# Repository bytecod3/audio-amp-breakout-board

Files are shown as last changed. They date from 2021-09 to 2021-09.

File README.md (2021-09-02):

## Class AB Audio Amplifier With TDA2030
### Introduction
The amplifier shown below uses the very versatile monolithic IC TDA2030 audio amplifier
to amplify the audio input from a 3.5mm Jack to power a subwoofer. It delivers an
output of 12W for 4 Ohm speaker and 8W for a 8 Ohm speaker.

### Schematic
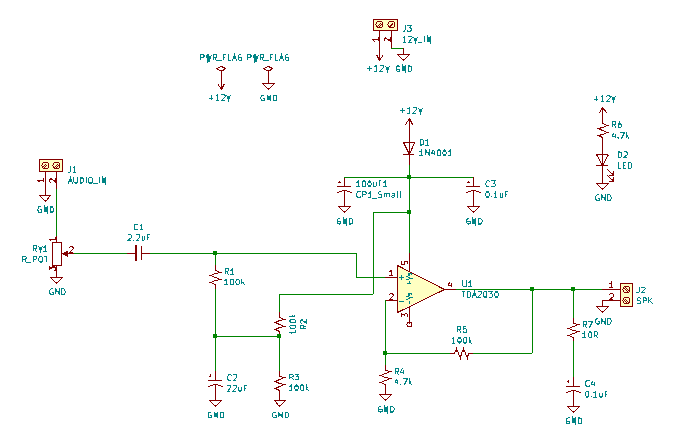
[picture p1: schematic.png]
Schematic


From the AUDIO_IN input, RV1 is a volume control knob. The amplifier is DC coupled
with C1. C1 and R1 form a high pass filter network to allow high freq signals
to be amplified.

TDA2030 is powered with 12V VCC. The 1N4001 Diode is a reverse protection component
to prevent the capacitors CP1 and C3 from getting damaged. R2 is a potential divider to bias the IC.

CP1, C3 and C2 are noise filters. 

The gain for this circuit is set by R5 and R4 and is given by: -R5/R4, which in this
case gives 25.6 dB. 

The series network formed by R7 and C4 is a Zobel network used to correct some of the 
internal amplifier inefficiencies. 

### Layout  

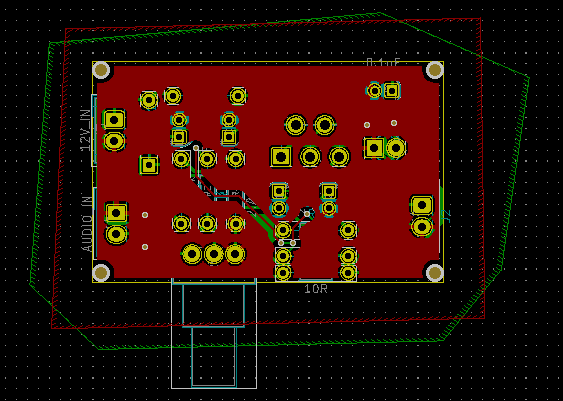
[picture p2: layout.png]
Layout


There are ground copper fills on both the front and back copper sides to drive the 
noise to ground and prevent background hissing

### 3D view

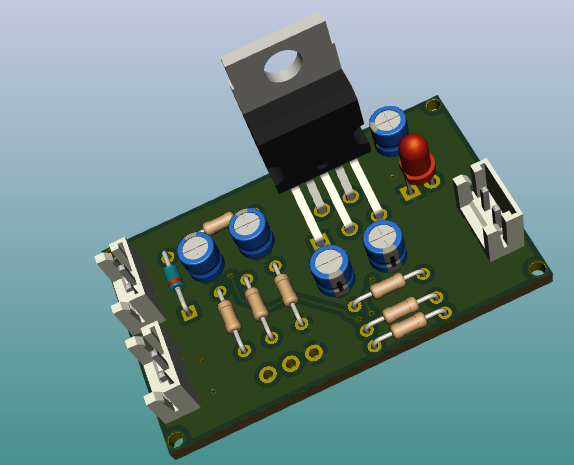
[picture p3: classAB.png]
view


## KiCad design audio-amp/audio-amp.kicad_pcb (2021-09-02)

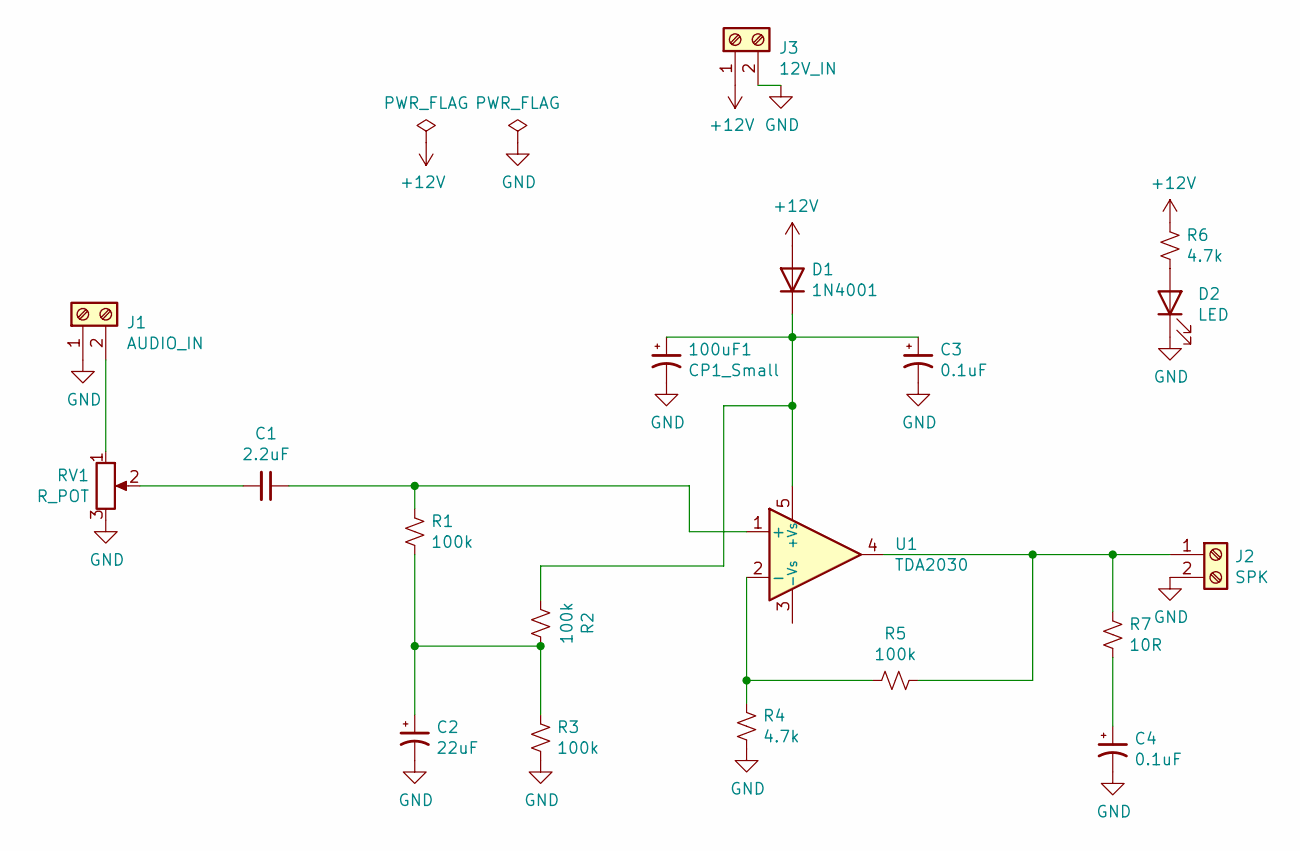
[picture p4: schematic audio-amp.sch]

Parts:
100uF1: CP1_Small; CP_Radial_D4.0mm_P2.00mm
C1: 2.2uF; CP_Radial_D4.0mm_P2.00mm
C2: 22uF; CP_Radial_D4.0mm_P2.00mm
C3, C4: 0.1uF; CP_Radial_D4.0mm_P2.00mm
D1: 1N4001; D_DO-34_SOD68_P7.62mm_Horizontal
D2: LED; LED_D3.0mm
J1: AUDIO_IN; JST_EH_B2B-EH-A_1x02_P2.50mm_Vertical
J2: SPK; JST_EH_B2B-EH-A_1x02_P2.50mm_Vertical
J3: 12V_IN; JST_EH_B2B-EH-A_1x02_P2.50mm_Vertical
R1, R2, R3, R5: 100k; R_Axial_DIN0204_L3.6mm_D1.6mm_P7.62mm_Horizontal
R4, R6: 4.7k; R_Axial_DIN0204_L3.6mm_D1.6mm_P7.62mm_Horizontal
R7: 10R; R_Axial_DIN0204_L3.6mm_D1.6mm_P7.62mm_Horizontal
RV1: R_POT; Potentiometer_Alps_RK09Y11_Single_Horizontal
U1: TDA2030; TO-220-5_P3.4x3.7mm_StaggerOdd_Lead3.8mm_Vertical

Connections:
+12V: D1.2 (A), J3.1, R6.2
GND: 100uF1.2, C2.2, C3.2, C4.2, D2.1 (K), J1.1, J2.2, J3.2, R3.1, R4.1, RV1.3
unnamed: 100uF1.1, C3.1, D1.1 (K), R2.2, U1.5 (+Vs)
unnamed: C1.1, R1.2, U1.1 (+)
unnamed: C1.2, RV1.2
unnamed: C2.1, R1.1, R2.1, R3.2
unnamed: C4.1, R7.1
unnamed: D2.2 (A), R6.1
unnamed: J1.2, RV1.1
unnamed: J2.1, R5.1, R7.2, U1.4
unnamed: R4.2, R5.2, U1.2 (-)

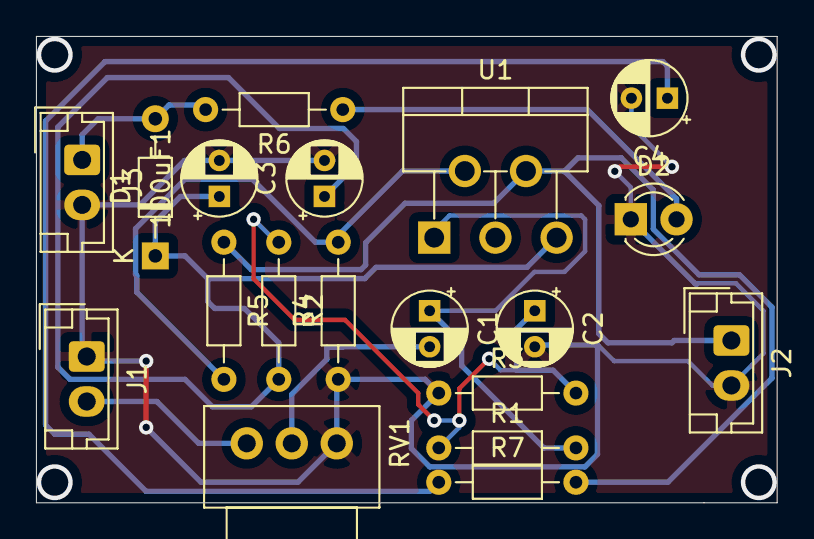
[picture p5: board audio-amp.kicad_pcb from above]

Board: 2 copper layers, 41.1 x 25.9 mm, 19 parts (0 on the bottom side), 11 nets.
